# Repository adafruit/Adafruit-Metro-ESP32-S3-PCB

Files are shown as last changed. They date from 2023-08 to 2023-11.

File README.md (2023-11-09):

## Adafruit Metro ESP32-S3 with 16 MB Flash 8MB PSRAM PCB

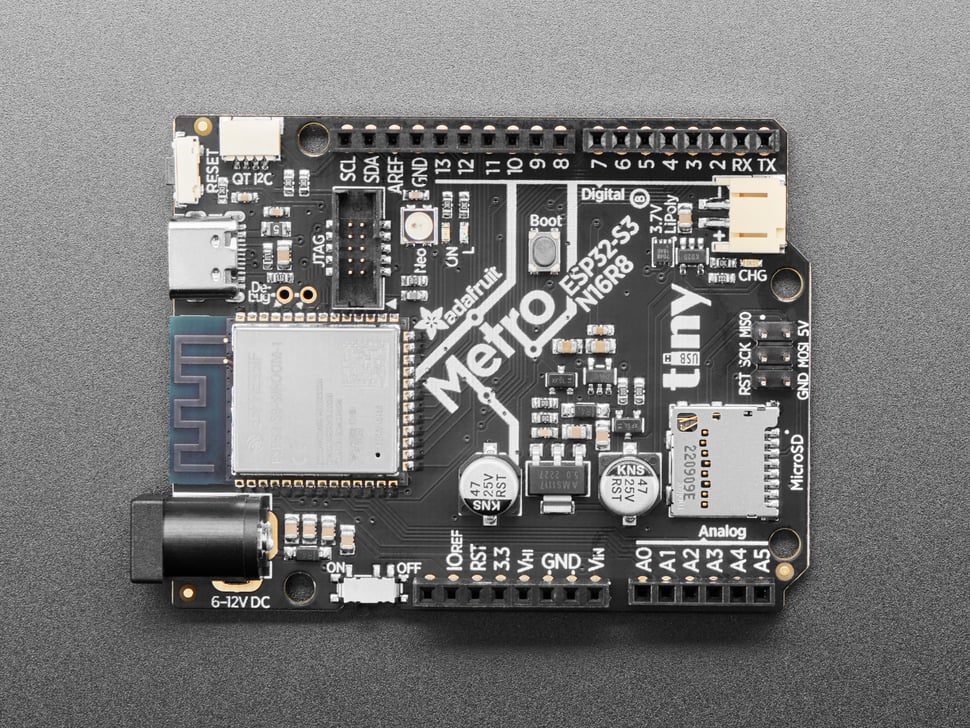
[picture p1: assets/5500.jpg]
<a href="http://www.adafruit.com/products/5500"><br/>
Click here to purchase one from the Adafruit shop</a>

PCB files for the Adafruit Metro ESP32-S3 with 16 MB Flash 8MB PSRAM. 

Format is EagleCAD schematic and board layout
* https://www.adafruit.com/product/5500

### Description

What's Metro-shaped and has an ESP32-S3 WiFi module? What has a STEMMA QT connector for I2C devices and a Lipoly charger circuit? What has your favorite Espressif WiFi microcontroller and lots of memory for your next IoT project?

That's right - it's the new Adafruit Metro ESP32-S3! With native USB and a load of PSRAM, this board is perfect for use with CircuitPython or Arduino to add low-cost WiFi while retaining shield compatibility.

The ESP32-S3 is a highly-integrated, low-power, 2.4 GHz Wi-Fi/BLE System-on-Chip (SoC) solution that has built-in native USB as well as some other interesting new technologies like Time of Flight distance measurements and AI acceleration. With its state-of-the-art power and RF performance, this SoC is an ideal choice for a wide variety of application scenarios relating to the Internet of Things (IoT), wearable electronics, and smart homes.

The Metro ESP32-S3 has a dual-core 240 MHz chip, so it is comparable to ESP32's dual-core. However, there is no Bluetooth Classic support, only Bluetooth LE. This chip is a great step up from the earlier ESP32-S2! This ESP32-S3 mini-module we are using on the Metro comes with massive 16 MB flash and 8 MB PSRAM, as well as lots of 512KB of SRAM so it's perfect for use with CircuitPython support or any time massive buffers are needed: for fast memory access use SRAM, for slower-but-roomier access use PSRAM. It's also great for use in ESP-IDF or with Arduino support.

Features:

* ESP32-S3 Dual Core 240MHz Tensilica processor - the next generation of ESP32-Sx, with native USB so it can act like a keyboard/mouse, MIDI device, disk drive, etc!
* Mini module has FCC/CE certification and comes with 16 MByte of Flash, 8 MByte PSRAM
* Power options - USB type C or Lipoly battery
* Built-in battery charging when powered over USB-C
* LiPoly battery monitor - MAX17048 chip actively monitors your battery for voltage and state of charge / percentage reporting over I2C
* Reset and DFU (BOOT0) buttons to get into the ROM bootloader (which is a USB serial port so you don't need a separate cable!)
* JTAG 2x5 Header for more intense debugging
* Serial debug output pins (optional, for checking the hardware serial debug console)
* STEMMA QT connector for I2C devices, with switchable power, so you can go into low power mode.
* On/Charge/User LEDs + status NeoPixel with pin-controlled power for low power usage
* Low Power friendly! In deep sleep mode we can get down to ~100uA of current draw from the Lipoly connection. Quiescent current is from the power regulator, ESP32-S3 chip, and Lipoly monitor. Turn off the NeoPixel and external I2C power for the lowest quiescent current draw.
* Works with ESP-IDF, Arduino or CircuitPython 

<b>As of Nov 8, 2023</b> - We've fixed this hardware to be revision B which has changed the NeoPixel pin and the SPI/SD card pins to no longer use the same pins as the octal PSRAM. Which means that the hardware now works correctly when PSRAM is activated! If you have a rev A hardware board, contact support to get a replacement rev B.

### License

Adafruit invests time and resources providing this open source design, please support Adafruit and open-source hardware by purchasing products from [Adafruit](https://www.adafruit.com)!

Designed by Limor Fried/Ladyada for Adafruit Industries.

Creative Commons Attribution/Share-Alike, all text above must be included in any redistribution. 
See license.txt for additional details.

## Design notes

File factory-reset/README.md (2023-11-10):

## Factory Reset file - Metro ESP32-S3 with 16 MB Flash 8MB PSRAM

This is the factory reset file for the Metro ESP32-S3 with 16 MB Flash 8MB PSRAM Rev B.

<b>As of Nov 8, 2023</b> - We've fixed this hardware to be revision B which has changed the NeoPixel pin and the SPI/SD card pins to no longer use the same pins as the octal PSRAM. This means that the hardware now works correctly when PSRAM is activated! <b>If you have a rev A hardware board, contact support to get a replacement rev B.</b>

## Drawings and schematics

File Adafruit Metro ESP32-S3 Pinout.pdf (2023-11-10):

# Adafruit Metro ESP32-S3

# https://www.adafruit.com/product/5500

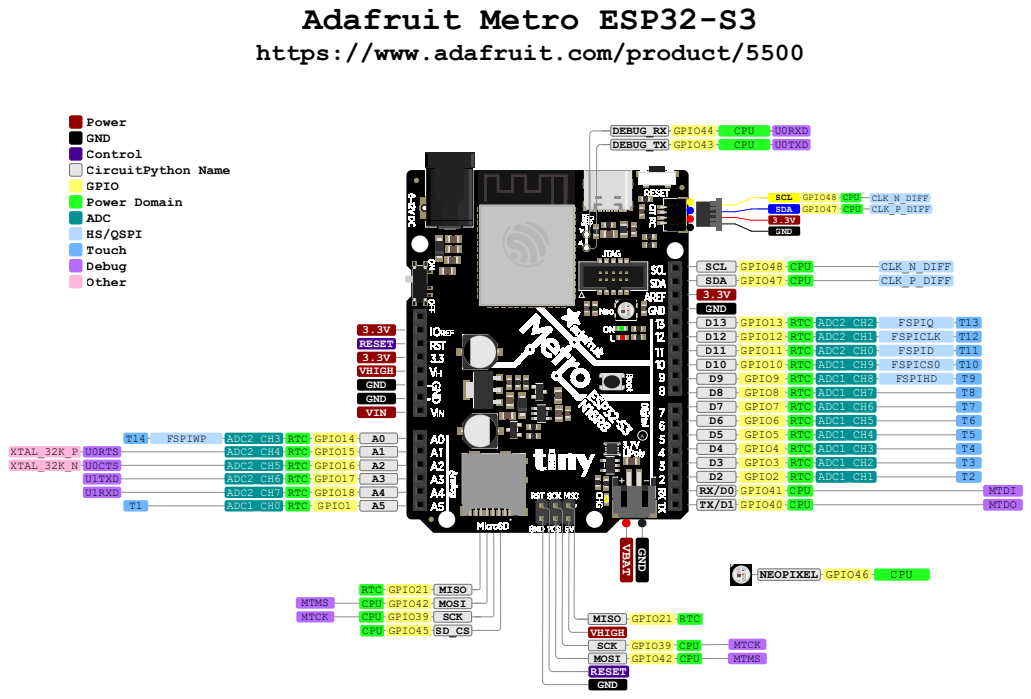
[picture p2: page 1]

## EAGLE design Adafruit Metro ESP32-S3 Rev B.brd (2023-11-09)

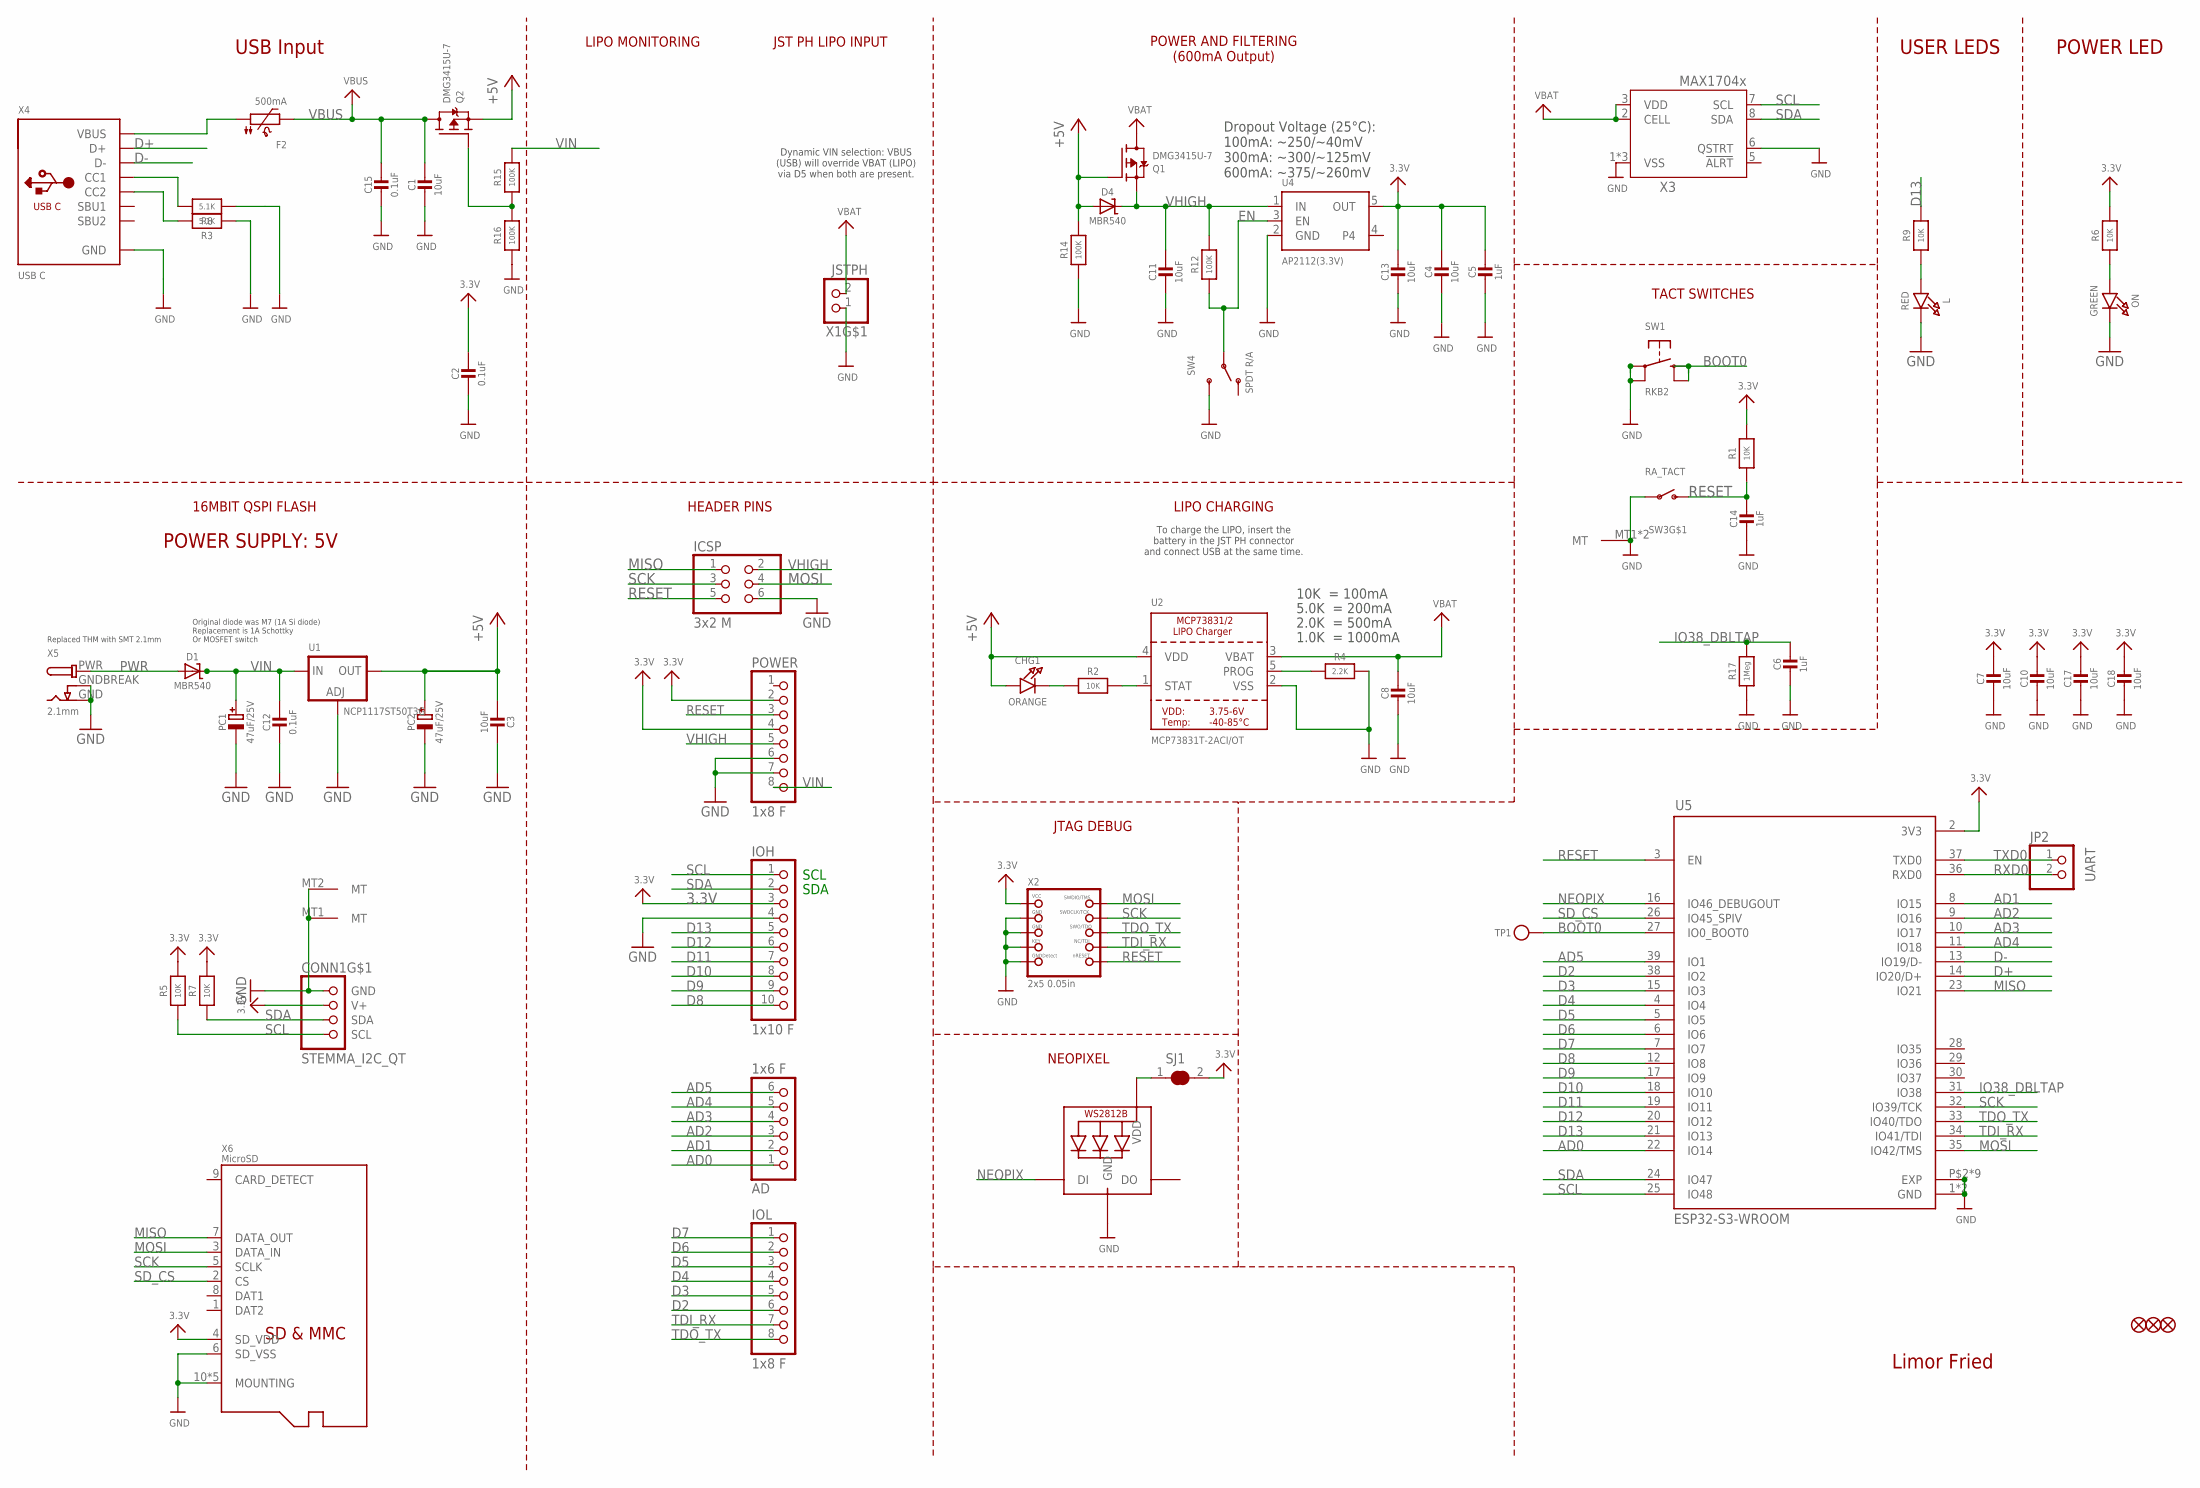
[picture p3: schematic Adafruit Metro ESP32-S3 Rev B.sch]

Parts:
AD: 1x6 F; 1X06_OVALWAVE
C1, C3, C4, C7, C8, C10, C11, C13, C17, C18: 10uF; 0805-NO
C2, C12, C15: 0.1uF; 0603-NO
C5, C6, C14: 1uF; 0603-NO
CHG1: ORANGE; CHIPLED_0603_NOOUTLINE
CONN1: STEMMA_I2C_QT; JST_SH4
D1, D4: MBR540; SOD-123
F2: 500mA; 0805-NO
FD1, FD2, FD3: FIDUCIAL_1MM
ICSP: 3x2 M; 2X03_ROUND_70MIL
IOH: 1x10 F; 1X10_OVALWAVE
IOL: 1x8 F; 1X08_OVALWAVE
JP2: UART; 1X02_ROUND
L: RED; CHIPLED_0603_NOOUTLINE
LED1: WS2812B_3535FULL; LED3535_FULLPADS
ON: GREEN; CHIPLED_0603_NOOUTLINE
PC1, PC2: 47uF/25V; PANASONIC_D
POWER: 1x8 F; 1X08_OVALWAVE
Q1, Q2: DMG3415U-7; SOT23-R
R1, R2, R5, R6, R7, R9: 10K; 0603-NO
R3, R8: 5.1K; 0603-NO
R4: 2.2K; 0603-NO
R12, R14, R15, R16: 100K; 0603-NO
R17: 1Meg; 0603-NO
SJ1: SOLDERJUMPER_CLOSED; SOLDERJUMPER_CLOSEDWIRE
SW1: RKB2; BTN_RKB2_4.6X2.8
SW3: RA_TACT; SPST_TACTILE_RA
SW4: SPDT R/A; SPDT_SMT_SSSS811101
TP1: TESTPOINTROUND1.5MMNO; TESTPOINT_ROUND_1.5MM_NO
U1: NCP1117ST50T3G; SOT223-R
U2: MCP73831T-2ACI/OT; SOT23-5
U4: AP2112(3.3V); SOT23-5; JLC_ROTATION 0
U5: ESP32-S3-WROOM; S3-WROOM32
X1: JSTPH; JSTPH2_BATT
X2: 2x5 0.05in; 2X05_1.27MM_BOX_POSTS
X3: MAX17048/T; TDFN8_2X2MM
X4: USB C; USB_C_CUSB31-CFM2AX-01-X
X5: 2.1mm; DCJACK_2MM_PTH
X6: MicroSD; MOLEX_104031-0811

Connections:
3.3V: C2.1, C4.1, C5.1, C7.1, C10.1, C13.1, C17.1, C18.1, CONN1.2 (V+), IOH.3, POWER.2, POWER.4, R1.2, R5.2, R6.2, R7.2, SJ1.2, U4.5 (OUT), U5.2 (3V3), X2.1 (VCC), X6.4 (SD_VDD)
+5V: C3.2, CHG1.A, D4.A, PC2.+, Q1.1 (G), Q2.2 (S), R14.2, U1.2 (OUT), U1.4 (OUT), U2.4 (VDD)
AD0: AD.1, U5.22 (IO14)
AD1: AD.2, U5.8 (IO15)
AD2: AD.3, U5.9 (IO16)
AD3: AD.4, U5.10 (IO17)
AD4: AD.5, U5.11 (IO18)
AD5: AD.6, U5.39 (IO1)
BOOT0: SW1.B (S), SW1.B' (S1), TP1.P$1, U5.27 (IO0_BOOT0)
D2: IOL.6, U5.38 (IO2)
D3: IOL.5, U5.15 (IO3)
D4: IOL.4, U5.4 (IO4)
D5: IOL.3, U5.5 (IO5)
D6: IOL.2, U5.6 (IO6)
D7: IOL.1, U5.7 (IO7)
D8: IOH.10, U5.12 (IO8)
D9: IOH.9, U5.17 (IO9)
D10: IOH.8, U5.18 (IO10)
D11: IOH.7, U5.19 (IO11)
D12: IOH.6, U5.20 (IO12)
D13: IOH.5, R9.2, U5.21 (IO13)
D+: U5.14 (IO20/D+), X4.A6 (D+), X4.B6 (D+)
D-: U5.13 (IO19/D-), X4.A7 (D-), X4.B7 (D-)
EN: R12.1, SW4.B, U4.3 (EN)
GND: C1.2, C2.2, C3.1, C4.2, C5.2, C6.2, C7.2, C8.2, C10.2, C11.2, C12.2, C13.2, C14.2, C15.2, C17.2, C18.2, CONN1.1 (GND), CONN1.MT1 (MT), CONN1.MT2 (MT), ICSP.6, IOH.4, L.C, LED1.4 (GND), ON.C, PC1.-, PC2.-, POWER.6, POWER.7, R3.1, R4.2, R8.1, R14.1, R16.1, R17.1, SW1.A, SW1.A' (P1), SW3.1, SW3.MT1 (MT), SW3.MT2 (MT), SW4.C (S), U1.1 (ADJ), U2.2 (VSS), U4.2 (GND), U5.1 (GND), U5.40 (GND), U5.P$2 (EXP), U5.P$3 (EXP), U5.P$4 (EXP), U5.P$5 (EXP), U5.P$6 (EXP), U5.P$7 (EXP), U5.P$8 (EXP), U5.P$9 (EXP), U5.P$10 (EXP), X1.1, X2.3 (GND), X2.5 (GND), X2.7 (KEY), X2.9 (GNDDETECT), X3.1 (VSS), X3.4 (VSS), X3.6 (QSTRT), X3.THERMAL (VSS), X4.A1B12 (GND), X4.B1A12 (GND), X5.GND, X5.GNDBREAK, X6.6 (SD_VSS), X6.10 (MOUNTING), X6.G1 (MOUNTING), X6.G2 (MOUNTING), X6.G3 (MOUNTING), X6.G4 (MOUNTING)
IO38_DBLTAP: C6.1, R17.2, U5.31 (IO38)
MISO: ICSP.1, U5.23 (IO21), X6.7 (DATA_OUT)
MOSI: ICSP.4, U5.35 (IO42/TMS), X2.2 (SWDIO), X6.3 (DATA_IN)
unnamed: L.A, R9.1
unnamed: Q2.1 (G), R15.1, R16.2
unnamed: ON.A, R6.1
unnamed: CHG1.C, R2.1
unnamed: LED1.2 (VDD), SJ1.1
unnamed: R2.2, U2.1 (STAT)
unnamed: R8.2, X4.A5 (CC1)
unnamed: R3.2, X4.B5 (CC2)
unnamed: R4.1, U2.5 (PROG)
unnamed: F2.1, X4.A4B9 (VBUS), X4.B4A9 (VBUS)
NEOPIX: LED1.1 (DI), U5.16 (IO46_DEBUGOUT)
PWR: D1.A, X5.PWR
RESET: C14.1, ICSP.5, POWER.3, R1.1, SW3.2 (S), U5.3 (EN), X2.10 (NRESET)
RXD0: JP2.2, U5.36 (RXD0)
SCK: ICSP.3, U5.32 (IO39/TCK), X2.4 (SWDCLK), X6.5 (SCLK)
SCL: CONN1.4 (SCL), IOH.1, R5.1, U5.25 (IO48), X3.7 (SCL)
SDA: CONN1.3 (SDA), IOH.2, R7.1, U5.24 (IO47), X3.8 (SDA)
SD_CS: U5.26 (IO45_SPIV), X6.2 (CS)
TDI_RX: IOL.7, U5.34 (IO41/TDI), X2.8 (TDI)
TDO_TX: IOL.8, U5.33 (IO40/TDO), X2.6 (SWO)
TXD0: JP2.1, U5.37 (TXD0)
VBAT: C8.1, Q1.3 (D), U2.3 (VBAT), X1.2, X3.2 (CELL), X3.3 (VDD)
VBUS: C1.1, C15.1, F2.2, Q2.3 (D)
VHIGH: C11.1, D4.C, ICSP.2, POWER.5, Q1.2 (S), R12.2, U4.1 (IN)
VIN: C12.1, D1.C, PC1.+, POWER.8, R15.2, U1.3 (IN)

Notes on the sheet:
SDA
SCL
Limor Fried
USB Input
POWER LED
USER LEDS
10K = 100mA
5.0K = 200mA
2.0K = 500mA
1.0K = 1000mA
LIPO CHARGING
LIPO MONITORING
To charge the LIPO, insert the battery in the JST PH connector and connect USB at the same time.
POWER AND FILTERING (600mA Output)
JST PH LIPO INPUT
Dynamic VIN selection: VBUS (USB) will override VBAT (LIPO) via D5 when both are present.
Dropout Voltage (25°C): 100mA: ~250/~40mV 300mA: ~300/~125mV 600mA: ~375/~260mV
HEADER PINS
16MBIT QSPI FLASH
TACT SWITCHES
JTAG DEBUG
NEOPIXEL
Original diode was M7 (1A Si diode) Replacement is 1A Schottky Or MOSFET switch
Replaced THM with SMT 2.1mm
POWER SUPPLY: 5V

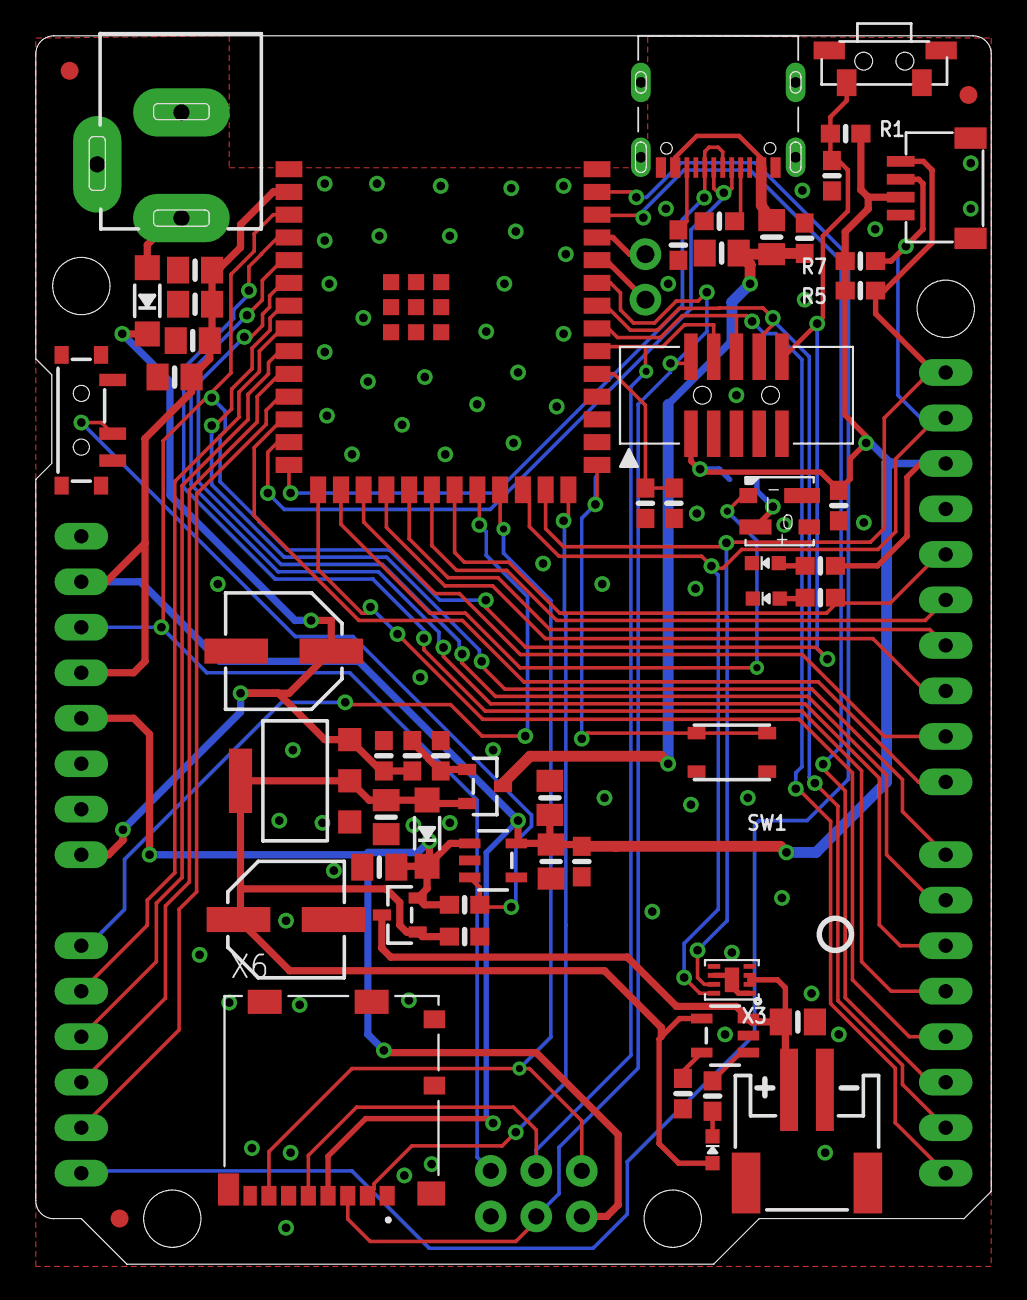
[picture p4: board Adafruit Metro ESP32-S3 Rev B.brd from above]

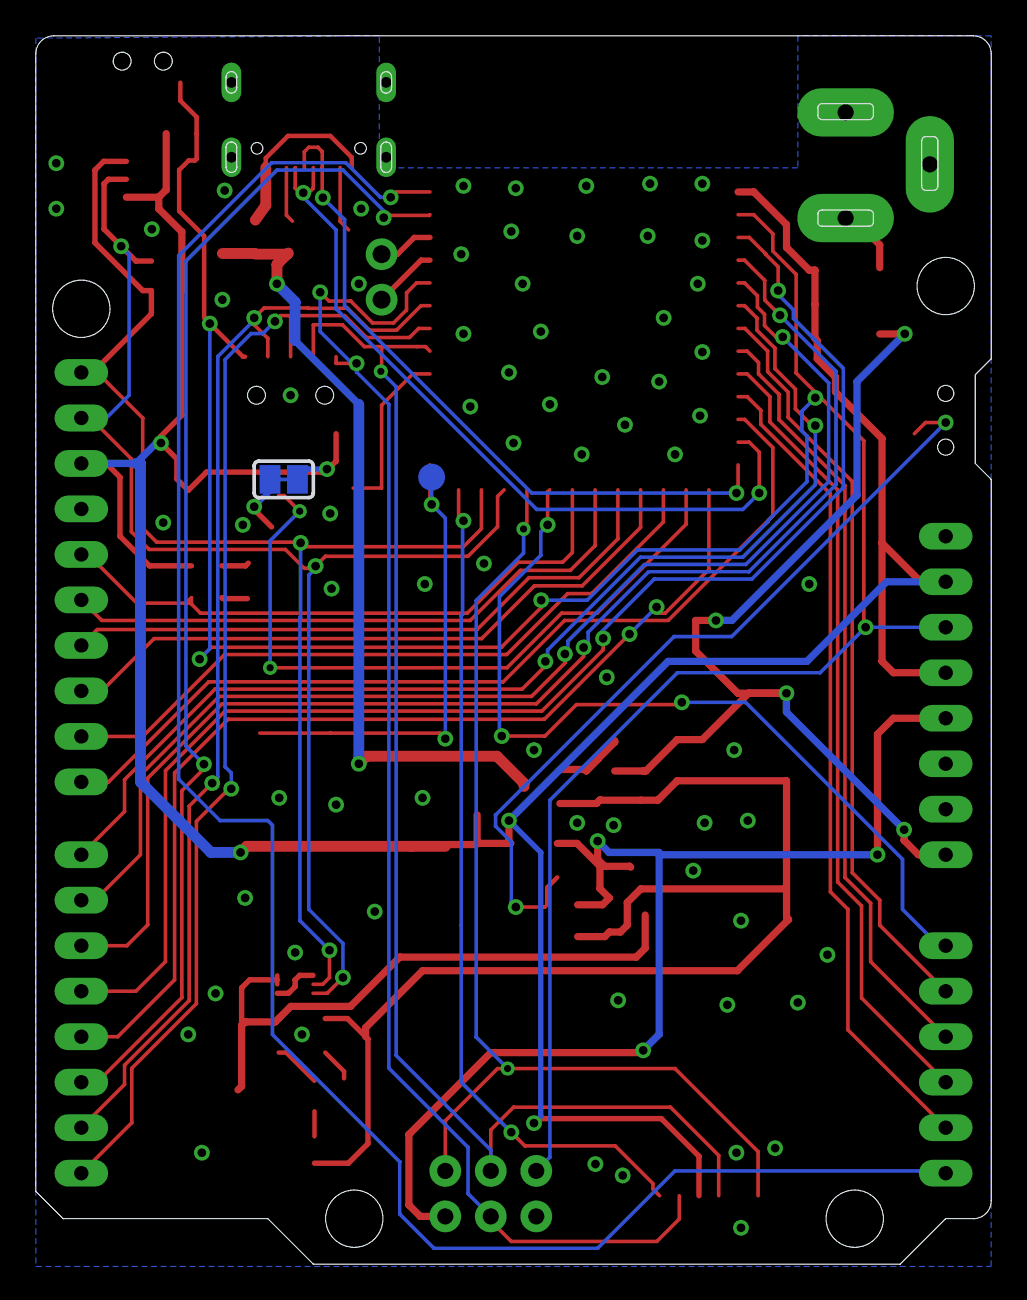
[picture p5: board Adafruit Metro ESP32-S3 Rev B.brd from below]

Board: 2 copper layers, 53.3 x 68.6 mm, 69 parts (3 on the bottom side), 53 nets.

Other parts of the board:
U$15: PCBFEAT-REV-040
U$52: METROS3_TOP
U$58: METROS3_BOT

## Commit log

2023-08-22 Add board files.
    [Adafruit Metro ESP32-S3.brd, Adafruit Metro ESP32-S3.sch]
2023-11-09 update for rev B
    [Adafruit Metro ESP32-S3 Rev A.brd, Adafruit Metro ESP32-S3 Rev A.sch, Adafruit Metro ESP32-S3 Rev B.brd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]

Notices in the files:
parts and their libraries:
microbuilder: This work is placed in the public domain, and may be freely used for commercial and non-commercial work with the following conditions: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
